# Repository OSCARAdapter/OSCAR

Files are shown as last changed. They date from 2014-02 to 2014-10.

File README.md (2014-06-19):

OSCAR
=====
A Retina screen controlling interface.

This repository contains the software for the host computer program, and the Arduino-ized firmware for the ATMega on board.
This repostiory also contais the schematics and board files.
This repository does not contain the new Aruduino variant required to build this code - but it can be found as a submodule.

Getting Started (from Source)
-----------------------------
1. `git clone https://github.com/OSCARAdapter/OSCAR.git`
2. `git submodule init && git submodule update`

*Build the firmware [in fw/]*
* `make`

*Program to the device.*

You may need to adjust MONITOR_PORT in fw/Makefile.
* `make upload`

*Build the software [in sw/] (_Windows_)*

This requires you to have Visual Studio C++ installed, the QT5 development environment to be set up, and to have the libusb source.
1. `qmake -tp vc oscar.pro`
2. Open the generated vcproj in Visual Studio
3. Adjust as required to fit your environment
4. Build

*Build the software [in sw/] (_Linux/OSX_)*

This requires a C++ compiler, QT5 development libraries, libusb development package.
1. `qmake oscar.pro`
2. `make`

*Other*
On Windows, you will be required to install the drivers for the device, these can be found in installer/drivers.

Getting Started (from Binary - Windows only)
--------------------------------------------
1. Download the installer from here
2. Run the installer
3. Plug OSCAR in

Repository Overview
-------------------
*Arduino/*

Contains the custom OSCAR variant in hardware/arduino/cores/oscar.
This is based on the ATMega task sample, and runs two tasks:
1. USB Task - responsible for processing all USB packets 
2. Arduino Task - reponsible for maintaing the single-threaded Arduino compatible emulation layer.

*Arduino-Makefile/*

A makefile system to allow the compilation of the code without requiring the Arduino IDE. This project can be found at https://github.com/sudar/Arduino-Makefile.

*fw/*

Contains the firmware for the integrated ATmega. All of the OSCAR code can be found in fw/libs/AdapterBoard.* This keeps the top level oscar.ino clear of any unnecessary code, allowing you to directly extend the device as you require.
Libraries for backlight control and control of the RGB led can also be found in fw/libs/

*hw/*

Contains the schematics and pcb layouts for the driver board.

*installer/*

The [NSIS](http://nsis.sourceforge.net/Main_Page) installer for Windows can be found in oscar.nsi. installer/qtlib contains the required DLLs for Qt5 and libusb to be directly included with the generated oscar executable for the installer.
installer/drivers contains the required Windows drivers for XP and Vista/Win7/Win8 to interact with the libusb device.

*logo/*

Contains the OSCAR logo, which is included in the software

*sw/*

Has the control software for your computer. This code presents a GUI for Windows, Linux or OSX based upon Qt5 and libusb. The source code can be found in sw/src, UI designs can be found in src/ui.

Other Notes
-----------
*Generating 'Combined' file for programming*
You will need the Caterina-leonardo.hex file from the bootloaders section of the Arduino code. You will also need the fw.hex generated from this source.
You will also need the tool srec_cat (part of the SRecord suite of tools).
`srec_cat fw.hex -intel Caterina-leonardo.hex -intel -o combined.hex -intel`

Licensing
---------
The software and firmware is licensed under the BSD 3-Clause License (refer to COPYING).

The hardware is licensed under CC-BY-SA.

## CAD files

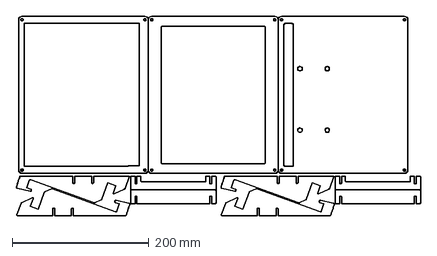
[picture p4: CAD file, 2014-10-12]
hw/case_v3_sheet1_tesselate_with_stand.dxf
591.7 x 291.6 mm

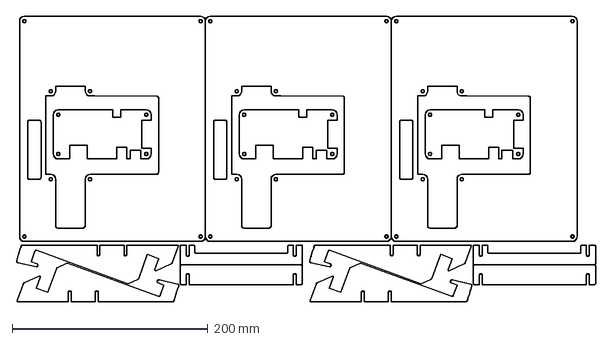
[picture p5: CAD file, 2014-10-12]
hw/case_v3_sheet2_tesselate_with_stand.dxf
591.7 x 291.6 mm

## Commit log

2014-02-08 Add raw arduino + makefile repos
2014-02-09 Add old arduino code
2014-02-09 Add switch pin definitions, fix pin for backlight
2014-02-09 Enable backlight power supply on/off
2014-02-09 Add support for the 3 switches
2014-02-09 Add makefile for use with Arduino-Makefile
2014-02-09 Fix PWM not changing
2014-02-09 Add buttons and bodges to mainwindow
2014-02-09 Fix board type and use custom core
2014-02-12 Add read-back support for RGB led
2014-02-12 Create a thread to handle device interaction in
    You would never do it in the UI thread (right?)
2014-02-12 Create a board-specific libusb'ing class
    Defines:
    - find the device
    - send a command (and get ack)
    - nothing else...
2014-02-16 Start device thread in mainwindow
2014-02-16 Define the devicethread
2014-02-16 Connect device connected/disconnected states
2014-02-17 Use public slots declarations
2014-02-17 Make deviceConnected/disconnected useful
2014-04-05 Bump Arduino subproject to include OSCAR variant
2014-05-24 Change Arduino submodule to refer to the OSCAR variant
2014-05-24 Add hardware
    [iPad_adapt_board.brd, iPad_adapt_board.sch]
2014-06-19 Prepare for release by building 32bit and test drivers
2014-07-02 Implement backlight and panel delays as given
    The datasheet for the LP097QX1-SPA1-8M1 states that the power must be
    provided prior to the backlight being enabled, and that the backlight
    must be disabled prior to the panel.
2014-07-03 Add latest case designs to hw/
2014-07-12 Set the LED on prior to the power to the display
    This provides a more 'responsive' UI for the user
2014-07-12 Fix: LED was not changed when toggled via USB
2014-07-12 Increase button delay by 5x
2014-07-12 Set LED off before backlight
2014-07-13 Change to use millis() to ensure minimum time between switch polls
2014-07-13 Revert "Change to use millis() to ensure minimum time between switch polls"
    This reverts commit 62b84387c85cd28378d28a473ed3bb4aa6b99e1e.
2014-07-13 Improve button debouncing using 2 history tracking
2014-07-13 Reduce LED power
2014-07-13 Latch power state for 300ms
2014-07-13 Only care about up/down switches if backlight is on
2014-07-13 Try to 'latch' up/down buttons
2014-07-13 Force switch polling to be at ~10ms intervals
2014-07-13 Revert "Force switch polling to be at ~10ms intervals"
    This reverts commit 5a4b9d49a8a98e4f83066dce59978ee33e38d56a.
2014-07-13 Revert "Try to 'latch' up/down buttons"
    This reverts commit 57e47e9f0008d73847a03f2e7c2a885c4ec899db.
2014-10-12 Production OSCAR board files
    [iPad_adapt_board.brd, iPad_adapt_board.sch]
2014-10-12 Revert "Production OSCAR board files"
    This reverts commit 5a923e2bebfcaec13dcdf26a45b099b8b35ddb17.
    [iPad_adapt_board.brd, iPad_adapt_board.sch]
2014-10-12 Case files in dxf added
    [case_v3_sheet1_tesselate_with_stand.dxf, case_v3_sheet2_tesselate_with_stand.dxf]
